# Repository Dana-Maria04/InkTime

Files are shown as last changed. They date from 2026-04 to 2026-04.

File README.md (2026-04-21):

# InkTime

## Block Diagram

Managed by the nRF52840 SoC, the device employs an RT6160 regulator to provide a steady 3.3V supply to all peripherals. The architecture combines an e-paper display and IMU with haptic feedback and dedicated user buttons.

Diagrama

## Bill of Materials (BOM)
| Qty | Value | Parts | Device | Package | Product Link | Datasheet Link |
| --: | --- | --- | --- | --- | --- | --- |
| 1 | nRF52840-QIAA | U1 | NORDIC_NRF_4_NRF52840_QF | AQFN-73-EP(7x7) | [JLCPCB](https://jlcpcb.com/partdetail/NordicSemicon-NRF52840_QIAAR/C190794) | [Datasheet](https://infocenter.nordicsemi.com/pdf/nRF52840_PS_v1.9.pdf) |
| 1 | BQ25180YBGR | IC1 | BQ25180YBGR | DSBGA-8(1.1x1.6) | [JLCPCB](https://jlcpcb.com/partdetail/TexasInstruments-BQ25180YBGR/C3682423) | [Datasheet](https://www.ti.com/lit/ds/symlink/bq25180.pdf) |
| 1 | MAX17048G+T10 | U3 | ESP32_C6_LIBRARY_MAX17048G+T10 | DFN-8-EP(2x2) | [JLCPCB](https://jlcpcb.com/partdetail/MaximIntegrated-MAX17048GT10/C2682616) | [Datasheet](https://www.analog.com/media/en/technical-documentation/data-sheets/MAX17048-MAX17049.pdf) |
| 1 | DRV2605YZFR | IC2 | DRV2605YZFR | DSBGA-9 | [JLCPCB](https://jlcpcb.com/partdetail/TexasInstruments-DRV2605YZFR/C81079) | [Datasheet](https://www.ti.com/lit/ds/symlink/drv2605.pdf) |
| 1 | DMG2305UX-7 | P-channel MOSFET | DMG2305UX-7 | SOT-23 | [JLCPCB](https://jlcpcb.com/partdetail/HXYMOSFET-DMG2305UX7/C5261054) | [Datasheet](https://www.diodes.com/assets/Datasheets/DMG2305UX.pdf) |
| 1 | SI1308EDL-T1-GE3  | Q3 | ESP32_C6_LIBRARY_6_SI1308EDL-T1-GE3 | SOT-323 | [JLCPCB](https://jlcpcb.com/partdetail/TECHPUBLIC-SI1308EDL/C7603347) | [Datasheet](https://www.vishay.com/docs/63399/si1308edl.pdf) |
| 3 | MBR0530 | D2, D4, D5 | MBR0530 | SOD-123 | [JLCPCB](https://jlcpcb.com/partdetail/4324765-MBR0530_F20000HF/C3757235) | [Datasheet](https://wmsc.lcsc.com/wmsc/upload/file/pdf/v2/lcsc/2205311800_Yangzhou-Yangjie-Electronic-Technology-MBR0530-F2-0000HF_C3757235.pdf) |
| 1 | USBLC6-2SC6Y | D3 | USBLC6-2SC6Y | SOT-23-6 | [JLCPCB](https://jlcpcb.com/partdetail/TECHPUBLIC-USBLC62SC6Y/C5310974) | [Datasheet](https://wmsc.lcsc.com/wmsc/upload/file/pdf/v2/lcsc/2401261525_TECH-PUBLIC-USBLC6-2SC6Y_C5310974.pdf) |
| 1 | 2450AT18B100E | ANT1 | 2450AT18B100E_2450AT18B100E | ANTC3216X140N / 1206 class | [JLCPCB](https://jlcpcb.com/partdetail/JohansonTechnology-2450AT18B100/C2836414) | [Datasheet](https://www.johansontechnology.com/datasheets/antennas/2450AT18B100.pdf) |
| 1 | KH-TYPE-C-16P | J4 | KH-TYPE-C-16P_KH-TYPE-C-16P | SMD | [JLCPCB](https://jlcpcb.com/partdetail/KH-TYPE-C-16P/C709357) | [Datasheet](https://wmsc.lcsc.com/wmsc/upload/file/pdf/v2/lcsc/2204251630_SHENZHEN-KINGHELM-Elec-KH-TYPE-C-16P_C709357.pdf) |
| 3 | EVP-AKE31A | SW_DN, SW_ENT, SW_UP | EVP-AKE31A | SW_EVP-AKE31A_PAN | [JLCPCB](https://jlcpcb.com/partdetail/PANASONIC-EVPAKE31A/C569760) | [Datasheet](https://www.lcsc.com/datasheet/C569760.pdf) |
| 1 | FTC252012SR47MBCA | L7 | MLP2016SR47MT0S1_FTC252012SR47MBCA  | INDC2016X100N | [JLCPCB](https://jlcpcb.com/partdetail/6763488-FTC252012SR47MBCA/C5832368) | [Datasheet](https://wmsc.lcsc.com/wmsc/upload/file/pdf/v2/lcsc/2311271530_TDK-FTC252012SR47MBCA_C5832368.pdf) |
| 1 | 32.768 kHz | X2 | NORDIC_NRF_1_XTAL_32KHZ | SMD3215-2P | [JLCPCB](https://jlcpcb.com/partdetail/NDK-NX3215SA_32_768K_STD_MUA9/C519280) | [Datasheet](https://www.ndk.com/images/products/crystal/resonator/NX3215SA_e.pdf) |
| 6 | 10K | R2_EP_DR, R5, R7, R8, R9, R_PWR_EPD | RC0201FR-1310KL | 0201 | [JLCPCB](https://jlcpcb.com/partdetail/YAGEO-RC0201FR1310KL/C6373588) | [Datasheet](https://www.lcsc.com/datasheet/C6373588.pdf) |
| 2 | 5K1 | R1_USB, R2_USB | RC0201FR-075K1L | 0201 | [JLCPCB](https://jlcpcb.com/partdetail/YAGEO-RC0201FR075K1L/C274341) | [Datasheet](https://www.lcsc.com/datasheet/C274341.pdf) |
| 2 | 3K3 | R17, R18 | RNCF0201DTC3K30 | 0201 | [JLCPCB](https://jlcpcb.com/partdetail/SEI_Stackpole_Elec-RNCF0201DTC3K30/C2487997) | [Datasheet](https://www.lcsc.com/datasheet/C2487997.pdf) |
| 3 | 0R | R2, R3, R4 | 0201WMJ0000TCE | 0201 | [JLCPCB](https://jlcpcb.com/partdetail/25793-0201WMJ0000TCE/C25050) | [Datasheet](https://www.lcsc.com/datasheet/C25050.pdf) |
| 1 | 2.2Î© | R_TYPE_SEL | 0201WMF220KTCE | 0201 | [JLCPCB](https://jlcpcb.com/partdetail/244650-0201WMF220KTCE/C247442) | [Datasheet](https://www.lcsc.com/datasheet/C247442.pdf) |
| 9 | 100nF | C5, C7, C8, C12, C19, C23, C27, C34, C42 | AC0201KRX6S6BB104 | 0201 | [JLCPCB](https://jlcpcb.com/partdetail/YAGEO-AC0201KRX6S6BB104/C3855913) | [Datasheet](https://www.lcsc.com/datasheet/C3855913.pdf) |
| 4 | 12pF | C1, C2, C17, C18 | 0201N120J250CT | 0201 | [JLCPCB](https://jlcpcb.com/partdetail/Walsin_TechCorp-0201N120J250CT/C424835) | [Datasheet](https://www.lcsc.com/datasheet/C424835.pdf) |
| 2 | 1pF | C3, C4 | GRM0335C1E1R0CA01J | 0201 | [JLCPCB](https://jlcpcb.com/partdetail/2274979-GRM0335C1E1R0CA01J/C2182912) | [Datasheet](https://www.lcsc.com/datasheet/C2182912.pdf) |
| 1 | 100pF | C11 | 0201N101F160CT | 0201 | [JLCPCB](https://jlcpcb.com/partdetail/Walsin_TechCorp-0201N101F160CT/C3847857) | [Datasheet](https://www.lcsc.com/datasheet/C3847857.pdf) |
| 1 | 47nF | C16 | C0201X5R473K160NTA | 0201 | [JLCPCB](https://jlcpcb.com/partdetail/126083-C0201X5R473K160NTA/C124806) | [Datasheet](https://www.lcsc.com/datasheet/C124806.pdf) |
| 1 | 1uF | C15 | CL05A105KP5NNNC | 0402 | [JLCPCB](https://jlcpcb.com/partdetail/C14445) | [Datasheet](https://www.lcsc.com/datasheet/C14445.pdf) |
| 5 | 4.7uF | C6, C14, C20, C21, C43 | GRM155R61A475KEAAD | 0402 | [JLCPCB](https://jlcpcb.com/partdetail/MurataElectronics-GRM155R61A475KEAAD/C77004) | [Datasheet](https://www.lcsc.com/datasheet/C77004.pdf) |
| 1 | 4.7uF / 25V | C2-EP-DR | C0402X5R475M250NT | 0402 | [JLCPCB](https://jlcpcb.com/partdetail/SANYEAR-C0402X5R475M250NT/C2911388) | [Datasheet](https://www.lcsc.com/datasheet/C2911388.pdf) |
| 9 | 1uF / 50V | EPD_C1, EPD_C2, EPD_C6, EPD_C7, EPD_C8, EPD_C9, EPD_C10, EPD_C11, EPD_C12 | GRM155R61H105KE05D | 0402 | [JLCPCB](https://jlcpcb.com/partdetail/1609005-GRM155R61H105KE05D/C1518208) | [Datasheet](https://www.lcsc.com/datasheet/C1518208.pdf) |
| 2 | 10uF | C24, C39 | 0402X106M100CT | 0402 | [JLCPCB](https://jlcpcb.com/partdetail/Walsin_TechCorp-0402X106M100CT/C2992625) | [Datasheet](https://www.lcsc.com/datasheet/C2992625.pdf) |
| 2 | 22uF | C25, C33 | CL05A226MQ6ZUN8 | 0402 | [JLCPCB](https://jlcpcb.com/partdetail/2889851-CL05A226MQ6ZUN8/C2762589) | [Datasheet](https://www.lcsc.com/datasheet/C2762589.pdf) |
| 1 | 820pF | C9 | MA0201XF821K250 | 0201 | [JLCPCB](https://jlcpcb.com/partdetail/Meritek-MA0201XF821K250/C3842403) | [Datasheet](https://www.lcsc.com/datasheet/C3842403.pdf) |
| 1 | 32MHz | X1 | NX2016SA-32MHZ-STD-CZS-5 | SMD2016-4P | [JLCPCB](https://jlcpcb.com/partdetail/NDK-NX2016SA_32MHZ_STD_CZS5/C843260) | [Datasheet](https://www.lcsc.com/datasheet/C843260.pdf) |
| 1 | 3.9nH | L1 | VHF060303H3N9ST | 0201 | [JLCPCB](https://jlcpcb.com/partdetail/153834-VHF060303H3N9ST/C142503) | [Datasheet](https://www.lcsc.com/datasheet/C142503.pdf) |
| 1 | 15nH | L3 | MLK0603L15NJT000 | 0201 | [JLCPCB](https://jlcpcb.com/partdetail/TDK-MLK0603L15NJT000/C6990407) | [Datasheet](https://www.lcsc.com/datasheet/C6990407.pdf) |
| 1 | BMA421 | IC3 | BMA421 | LGA-12(2x2) | [JLCPCB](https://jlcpcb.com/partdetail/BoschSensortec-BMA421/C5242966) | [Datasheet](https://files.pine64.org/doc/datasheet/pinetime/BST-BMA421-FL000.pdf) |
| 1 | RT6160AWSC | IC9 | RT6160AWSC | WLCSP-15B(2.3x1.4) | [JLCPCB](https://jlcpcb.com/partdetail/RichtekTech-RT6160AWSC/C7065276) | [Datasheet](https://www.mouser.com/datasheet/2/1458/DS6160A_03-3104604.pdf) |
| 1 | 503480-2400 | J1 | 5034802400 | 24-pin 0.5mm right-angle FPC | [JLCPCB](https://jlcpcb.com/partdetail/MOLEX-5034802400/C122434) | [Datasheet](https://www.mouser.com/datasheet/2/276/2/5034802400_FFC_FPC_CONNECTORS-1112921.pdf) |

## System Design and Hardware Implementation

The hardware architecture of the **InkTime Smartwatch** centers on the **nRF52840 microcontroller**, integrating five specialized sub-systems to create a high-efficiency wearable device.

### 1. Central SoC & Communication
The **nRF52840** handles all high-level logic, from sensor fusion to Bluetooth LE communication. It utilizes a **32 MHz crystal** for active processing and a **32.768 kHz crystal** for low-power timekeeping. For debugging and firmware updates, a **TC2030 SWD header** is included, exposing the `SWDIO` and `SWDCLK` lines.

### 2. Power Subsystem & Efficiency
Energy is managed through a multi-stage architecture:
* **USB-C Input:** Protected by **USBLC6-2SC6Y** ESD diodes to ensure safety during charging.
* **Management:** The **BQ25180 charger** regulates power flow between the USB source and the **Li-Po battery**.
* **Efficiency:** An **RT6160 Buck-Boost converter** ensures all peripherals receive exactly **3.3V**, regardless of battery discharge levels.
* **Monitoring:** The **MAX17048 fuel gauge** uses I2C to alert the MCU of low-battery conditions in real-time.

### 3. Specialized Sub-systems
* **Display:** The **1.54-inch E-Ink panel** uses an SPI interface. Its bi-stable nature allows it to hold an image without consuming power, drastically reducing the overall energy profile.
* **Motion & Interaction:** An **IMU (BMA421/423)** monitors activity, while three GPIO-mapped buttons manage user navigation and input.
* **Haptics:** Physical feedback for notifications is provided by a vibration motor controlled by the **DRV2605 driver**, which supports pre-programmed haptic patterns over I2C.

### 4. Energy Estimation
The system is optimized for an extremely low duty cycle:
* **Deep Sleep:** $< 10\text{µ}$.
* **Active Refresh:** $8\text{-}10\text{ mA}$ for approximately $1\text{-}2$ seconds per minute.

Based on the **250 mAh** battery capacity, the smartwatch achieves an autonomy of **over 9 days**, even with active sensor monitoring and daily haptic notifications. This performance highlights the synergy between the E-Ink technology and the nRF52's advanced power-saving features.

### Detailed Pinnout Map of nRF52840

| nRF52840 Pin | Connected Block | Signal Name | Purpose / Function |
| :--- | :--- | :--- | :--- |
| **P1.13** | E-paper Display | `MOSI` | SPI data output to display |
| **P1.15** | E-paper Display | `SCK` | SPI serial clock line |
| **P0.05** | E-paper Display | `EPD_CS` | SPI chip select (active low) |
| **P0.16** | E-paper Display | `EPD_DC` | Data/Command selection toggle |
| **P0.17** | E-paper Display | `EPD_RST` | Hardware reset for display |
| **P0.15** | E-paper Display | `EPD_BUSY` | Status feedback (busy/ready) |
| **P0.06** | I2C Bus (Shared) | `SDA` | Data line for IMU, Fuel Gauge, and Haptic |
| **P0.07** | I2C Bus (Shared) | `SCL` | Clock line for IMU, Fuel Gauge, and Haptic |
| **P0.08** | IMU (BMA42x) | `IMU_INT1` | Primary motion interrupt |
| **P1.08** | IMU (BMA42x) | `IMU_INT2` | Secondary motion interrupt |
| **P0.11** | PMIC (BQ25180) | `PMIC_INT` | Power-management status interrupt |
| **P0.24** | Fuel Gauge | `ALERT` | Battery fuel gauge status alert |
| **P0.12** | Haptic Driver | `HAPTIC_EN` | Enable and control for DRV2605 |
| **P0.13** | USB-C Interface | `D+` | USB differential data positive |
| **P0.14** | USB-C Interface | `D-` | USB differential data negative |
| **VBUS pin** | Charger / USB-C | `VBUS` | USB voltage presence detection |
| **SWDIO** | SWD Header | `SWDIO` | Bidirectional debug/programming data |
| **SWDCLK** | SWD Header | `SWDCLK` | Debug/programming clock reference |
| **P1.09** | SWD Header | `SWO` | Single Wire Output (trace debug) |
| **P0.18 / RESET** | SWD Header | `RESET` | Global hardware reset line |
| **ANT pin** | RF Network | `RF` | 2.4 GHz connection to chip antenna |

## Design Decisions & DRC/ERC Notes

### 1. Hardware Design Log
* **Space Optimization:** To fit the enclosure, a **1.0 mm PCB** was used with all components mounted on the **TOP layer**. The use of **0201 footprints** was critical for the high-density layout.
* **Signal Integrity:** **100 nF decoupling capacitors** are placed as close as possible ($< 0.5$ mm) to power pins. Power traces are widened to **0.3 mm** to ensure stable voltage delivery.
* **RF Layout:** The antenna is positioned on the board edge with a clear **Keep-out zone** (no copper on any layer) to maximize Bluetooth connectivity.

### 2. Validation & Manual Approvals
The following CAD warnings were reviewed and approved based on project constraints:

* **Mechanical Alignment (DRC):** Dimension errors for the **USB-C connector and tactile buttons** were ignored because their placement must match the pre-defined enclosure openings.
* **High-Density Routing (DRC):** Overlaps caused by **via-in-pad** and escape routing for the nRF52840 were accepted. This was the only way to route the MCU pins in the available space.
* **Net Connectivity (ERC):** "Only INPUT pins" warnings were verified; the schematic is functionally complete, and these are typical false positives in this project context.
* **Power Pins (ERC):** Power rail warnings were manually checked to ensure that the **RT6160** and **BQ25180** correctly supply the 3.3V and VBAT nets.

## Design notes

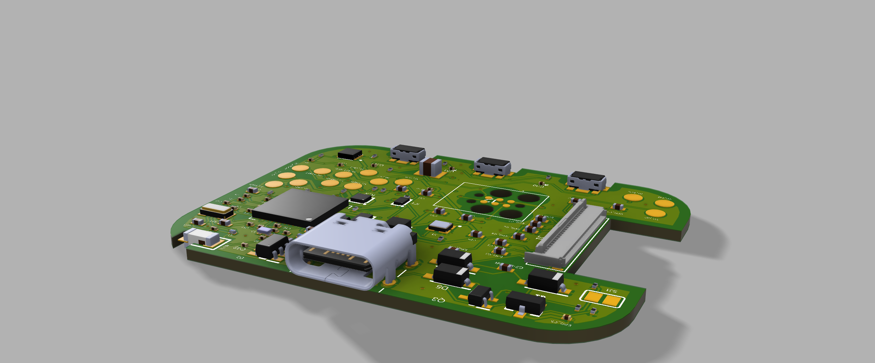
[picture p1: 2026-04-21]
Images/3D_PCB_View2.png

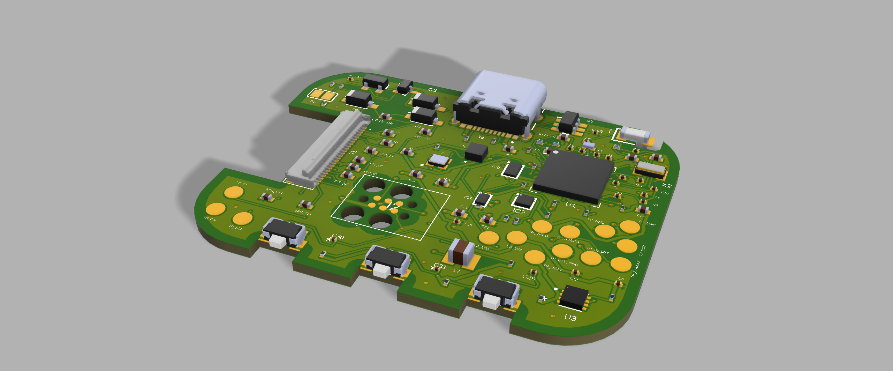
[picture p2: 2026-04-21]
Images/3D_PCB_View1.png

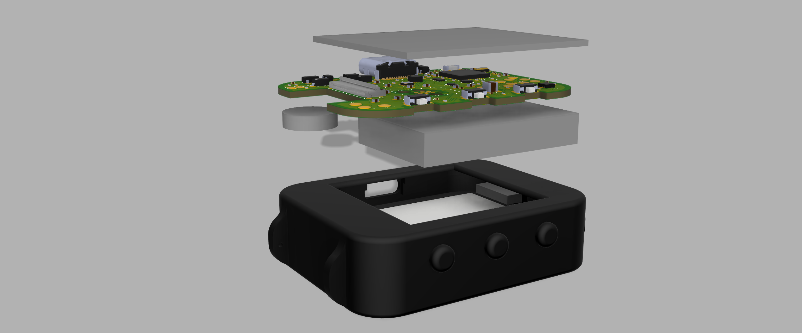
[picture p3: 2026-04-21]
Images/ExplodedView.png

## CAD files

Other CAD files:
Mechanical/InkTime_Assembly.f3z

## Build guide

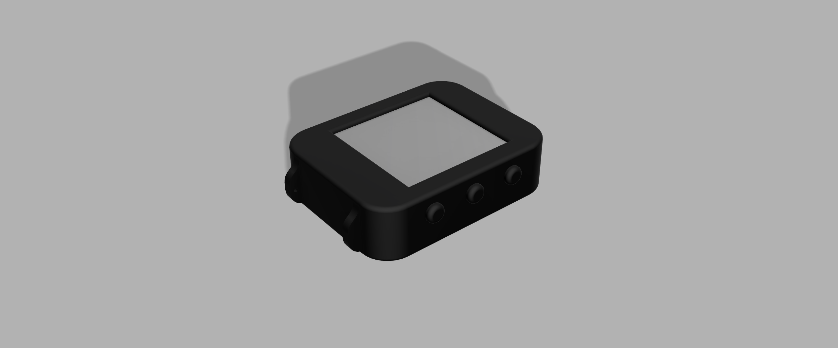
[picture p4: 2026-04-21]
Images/Assembly.png

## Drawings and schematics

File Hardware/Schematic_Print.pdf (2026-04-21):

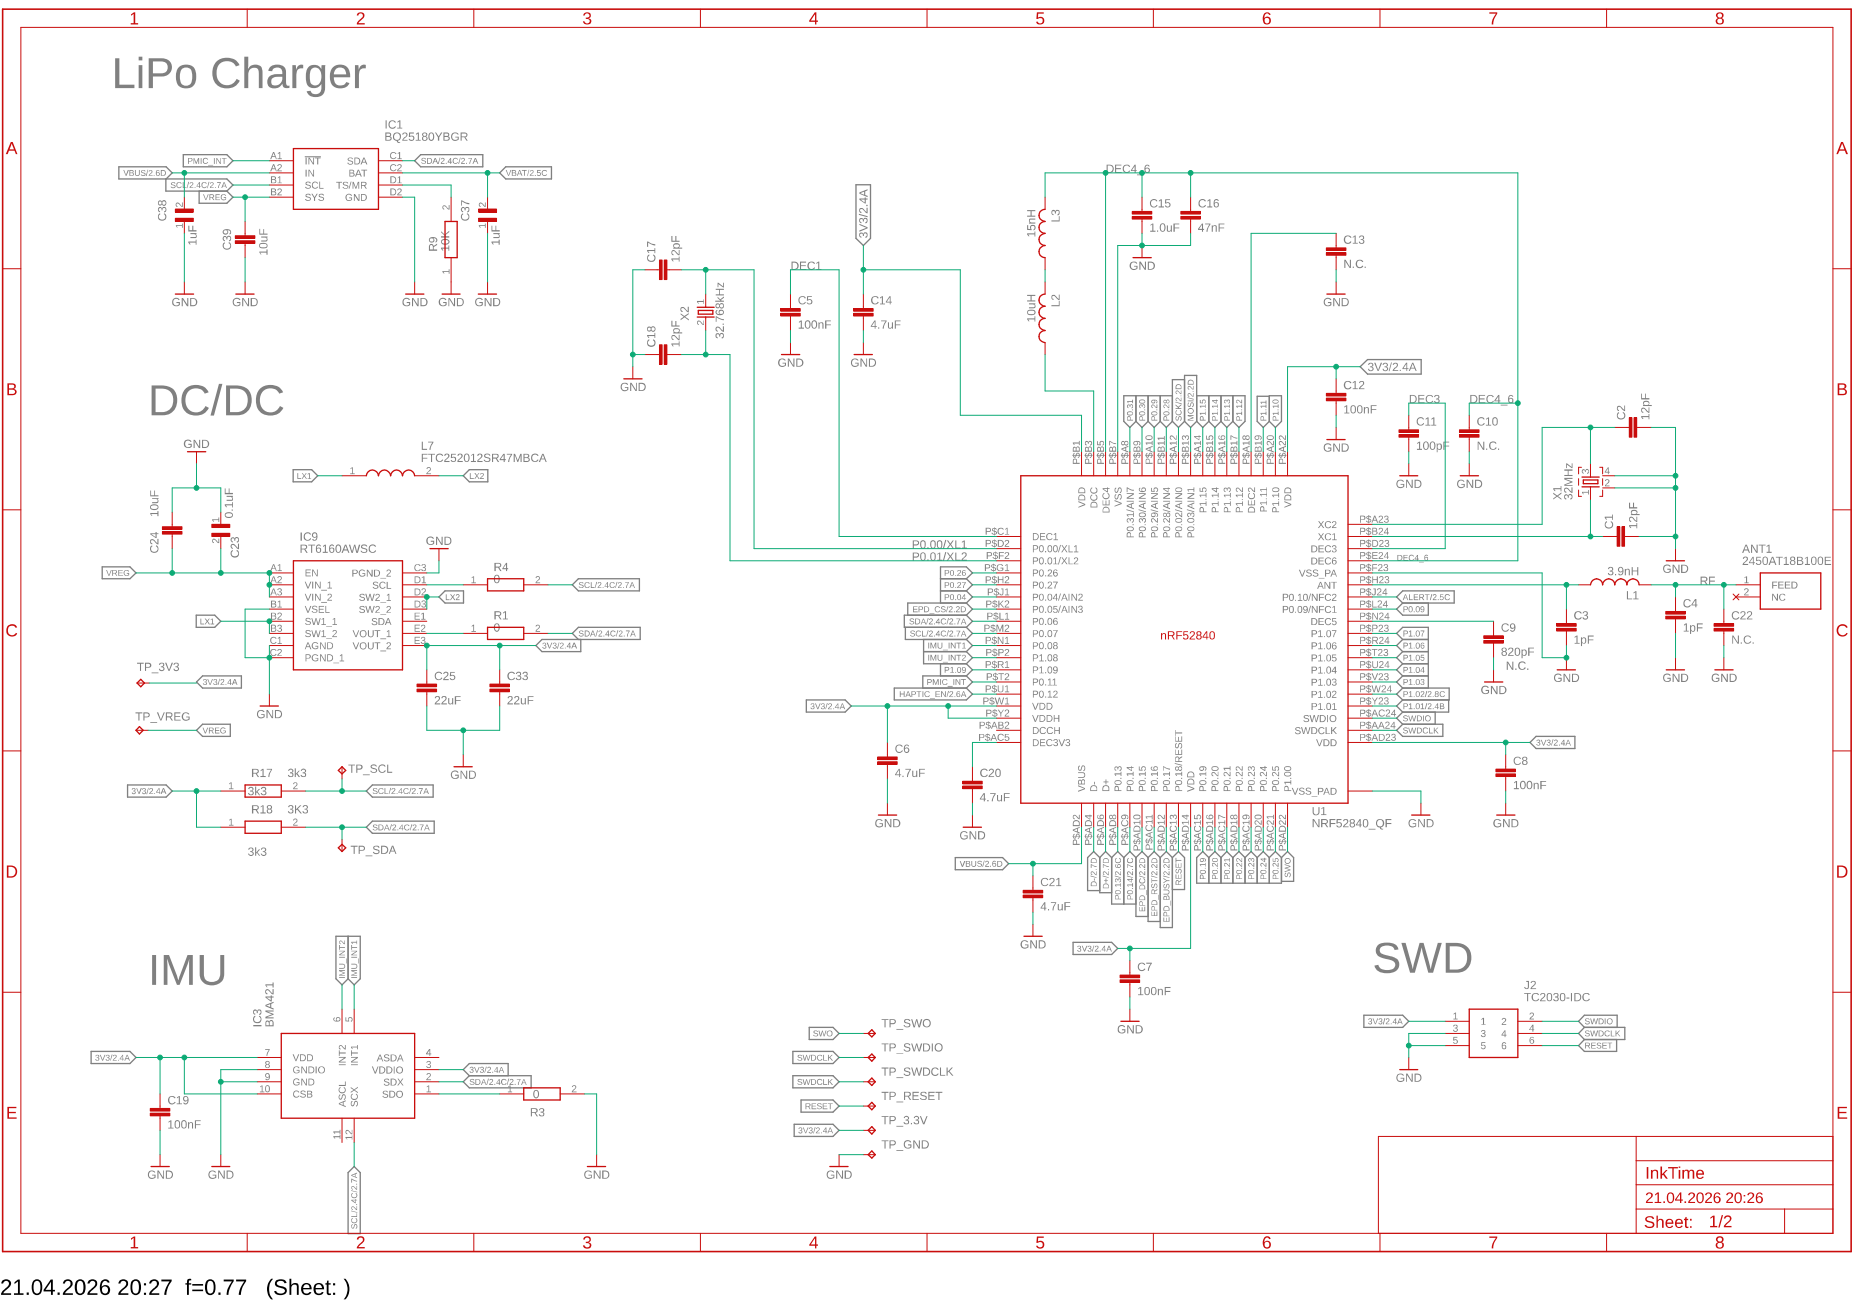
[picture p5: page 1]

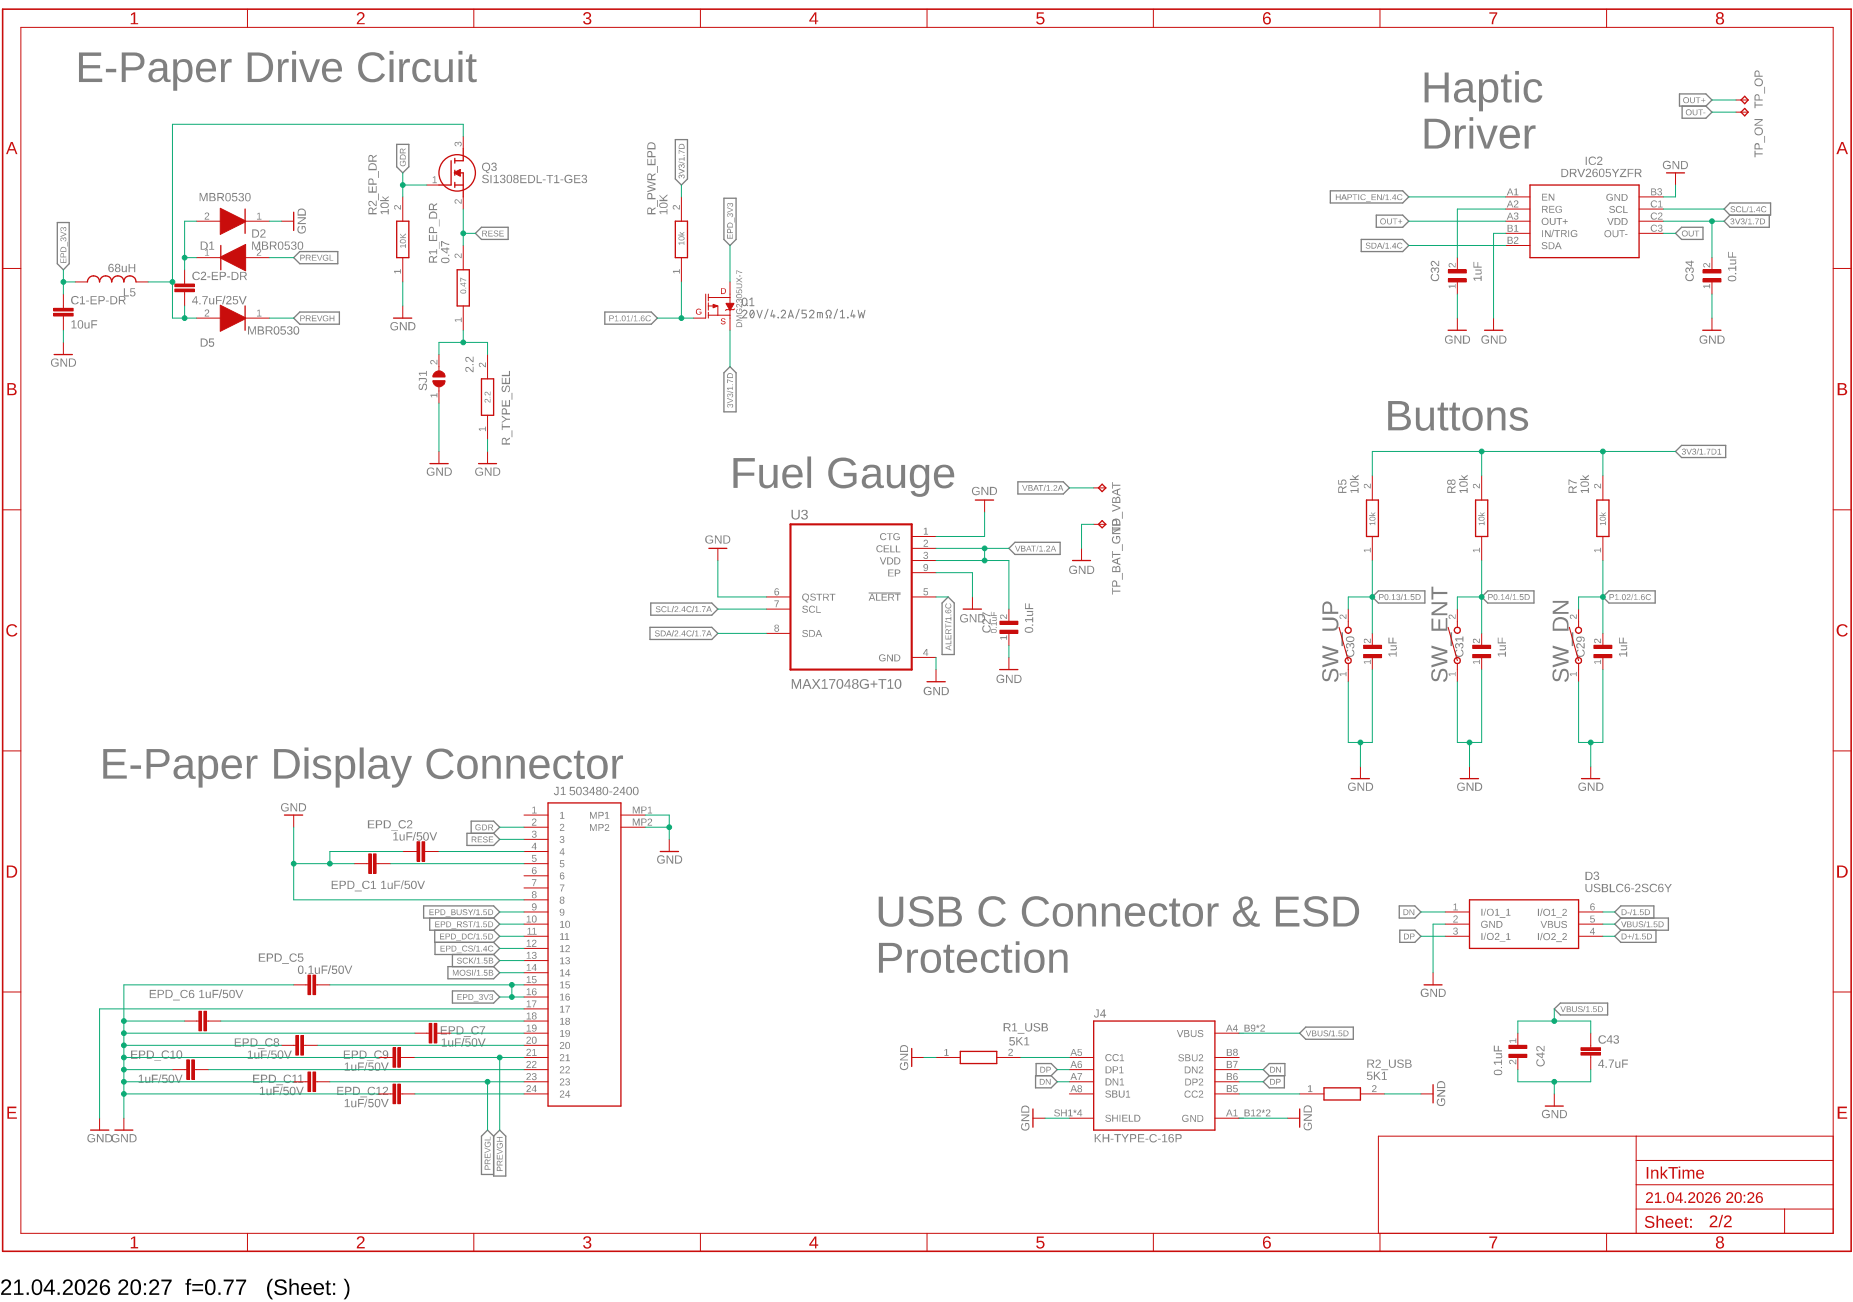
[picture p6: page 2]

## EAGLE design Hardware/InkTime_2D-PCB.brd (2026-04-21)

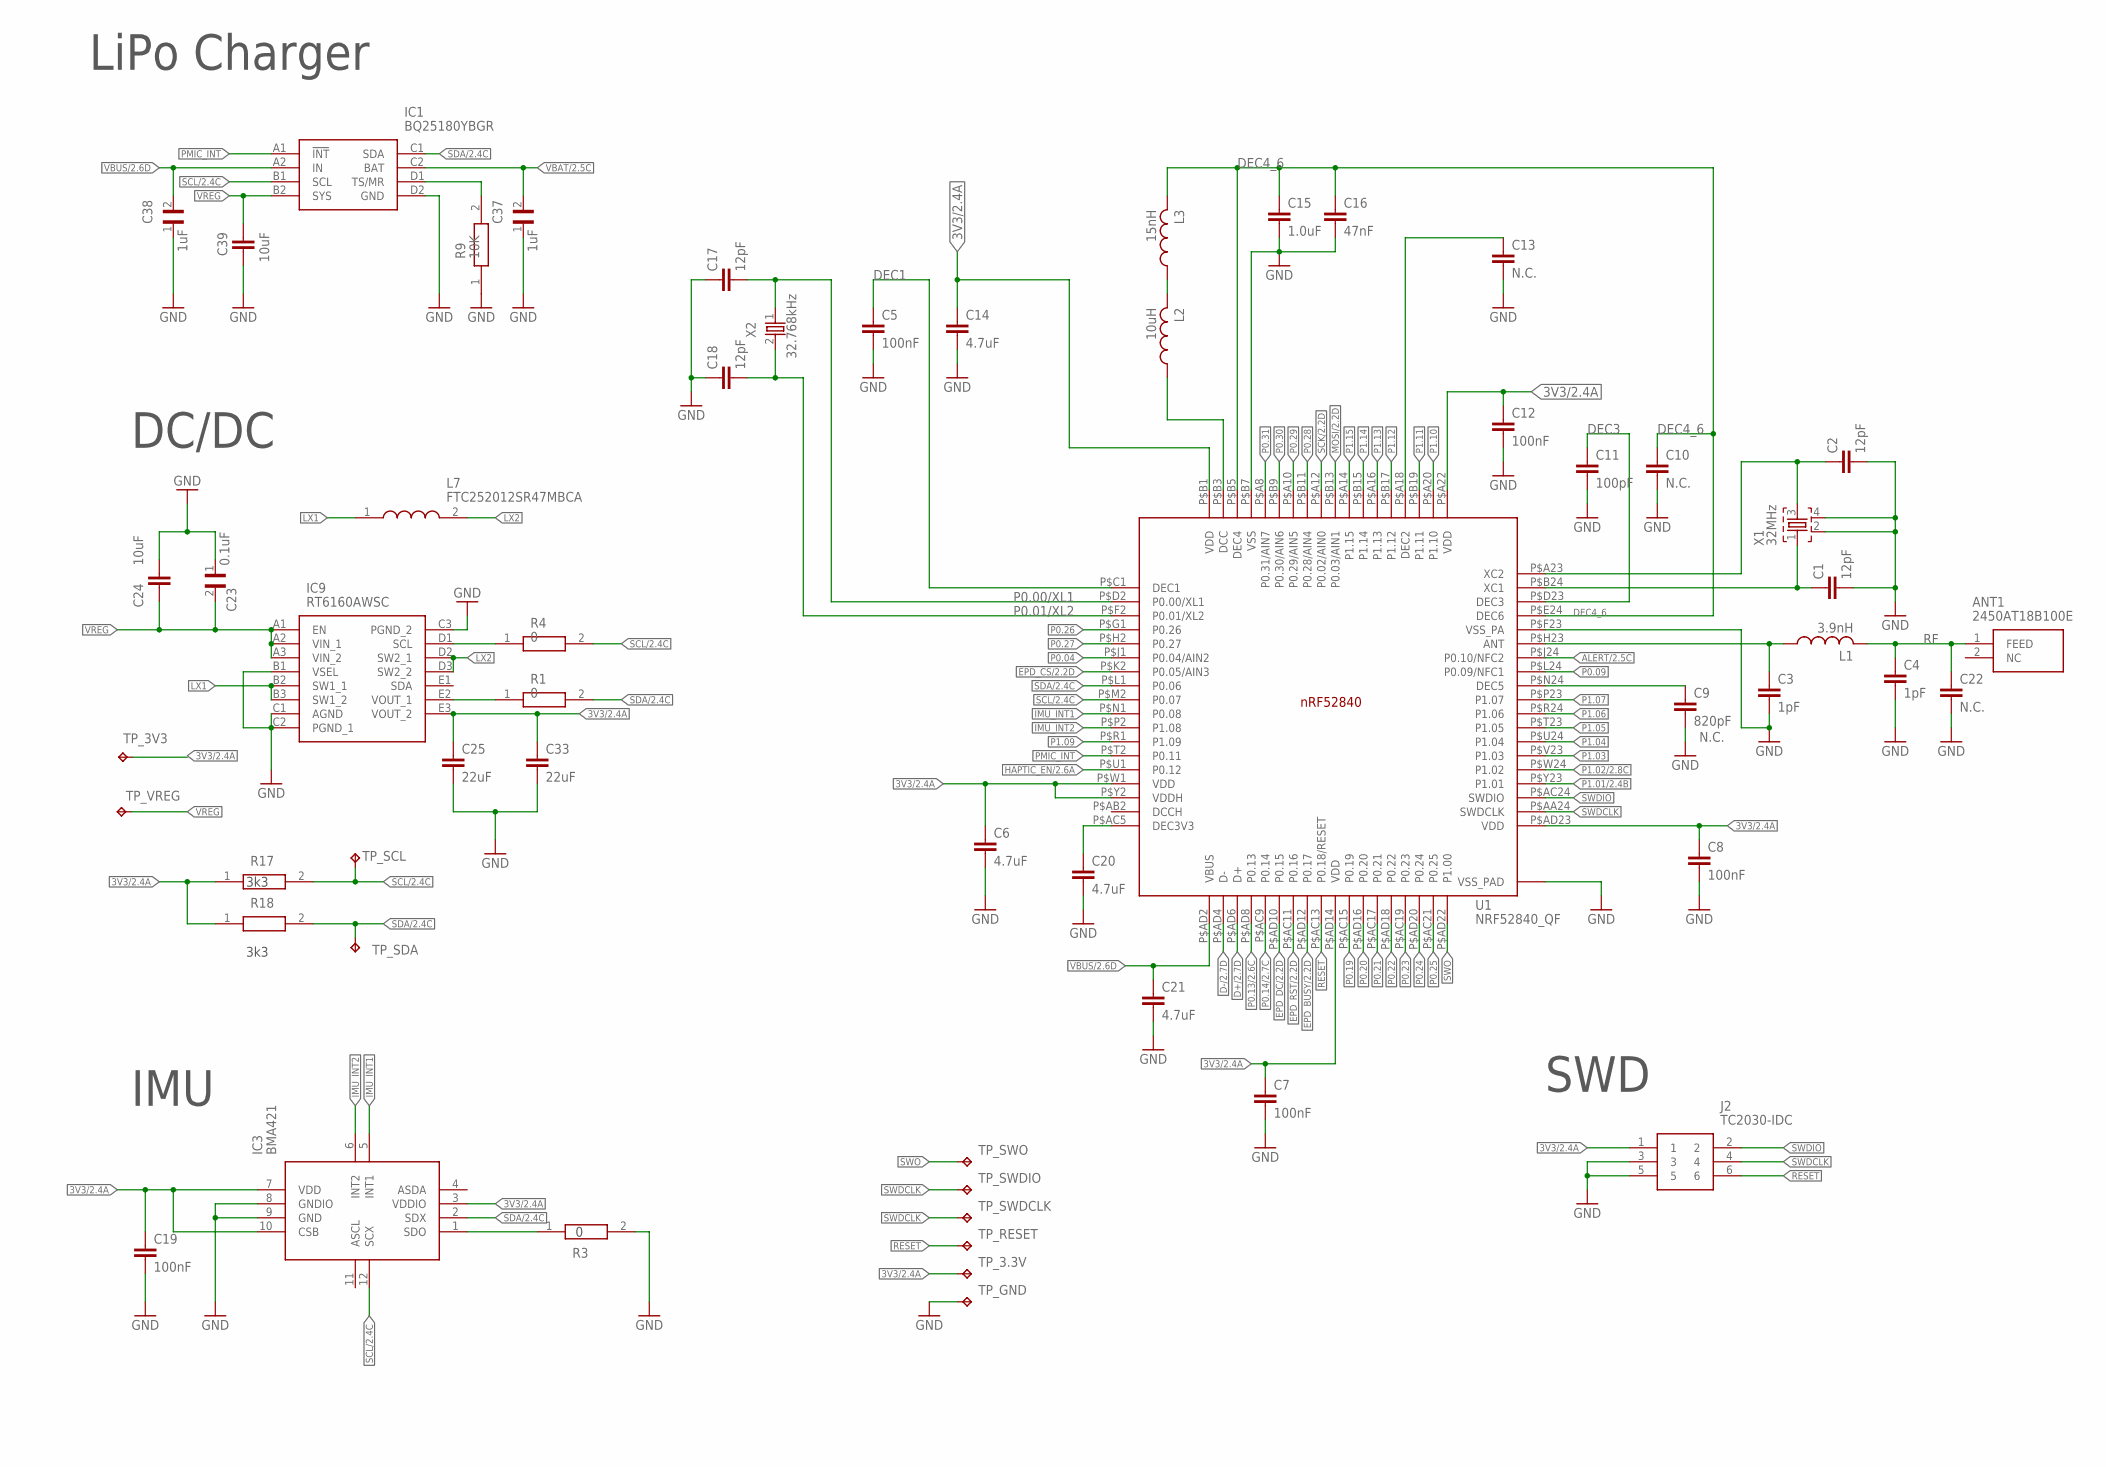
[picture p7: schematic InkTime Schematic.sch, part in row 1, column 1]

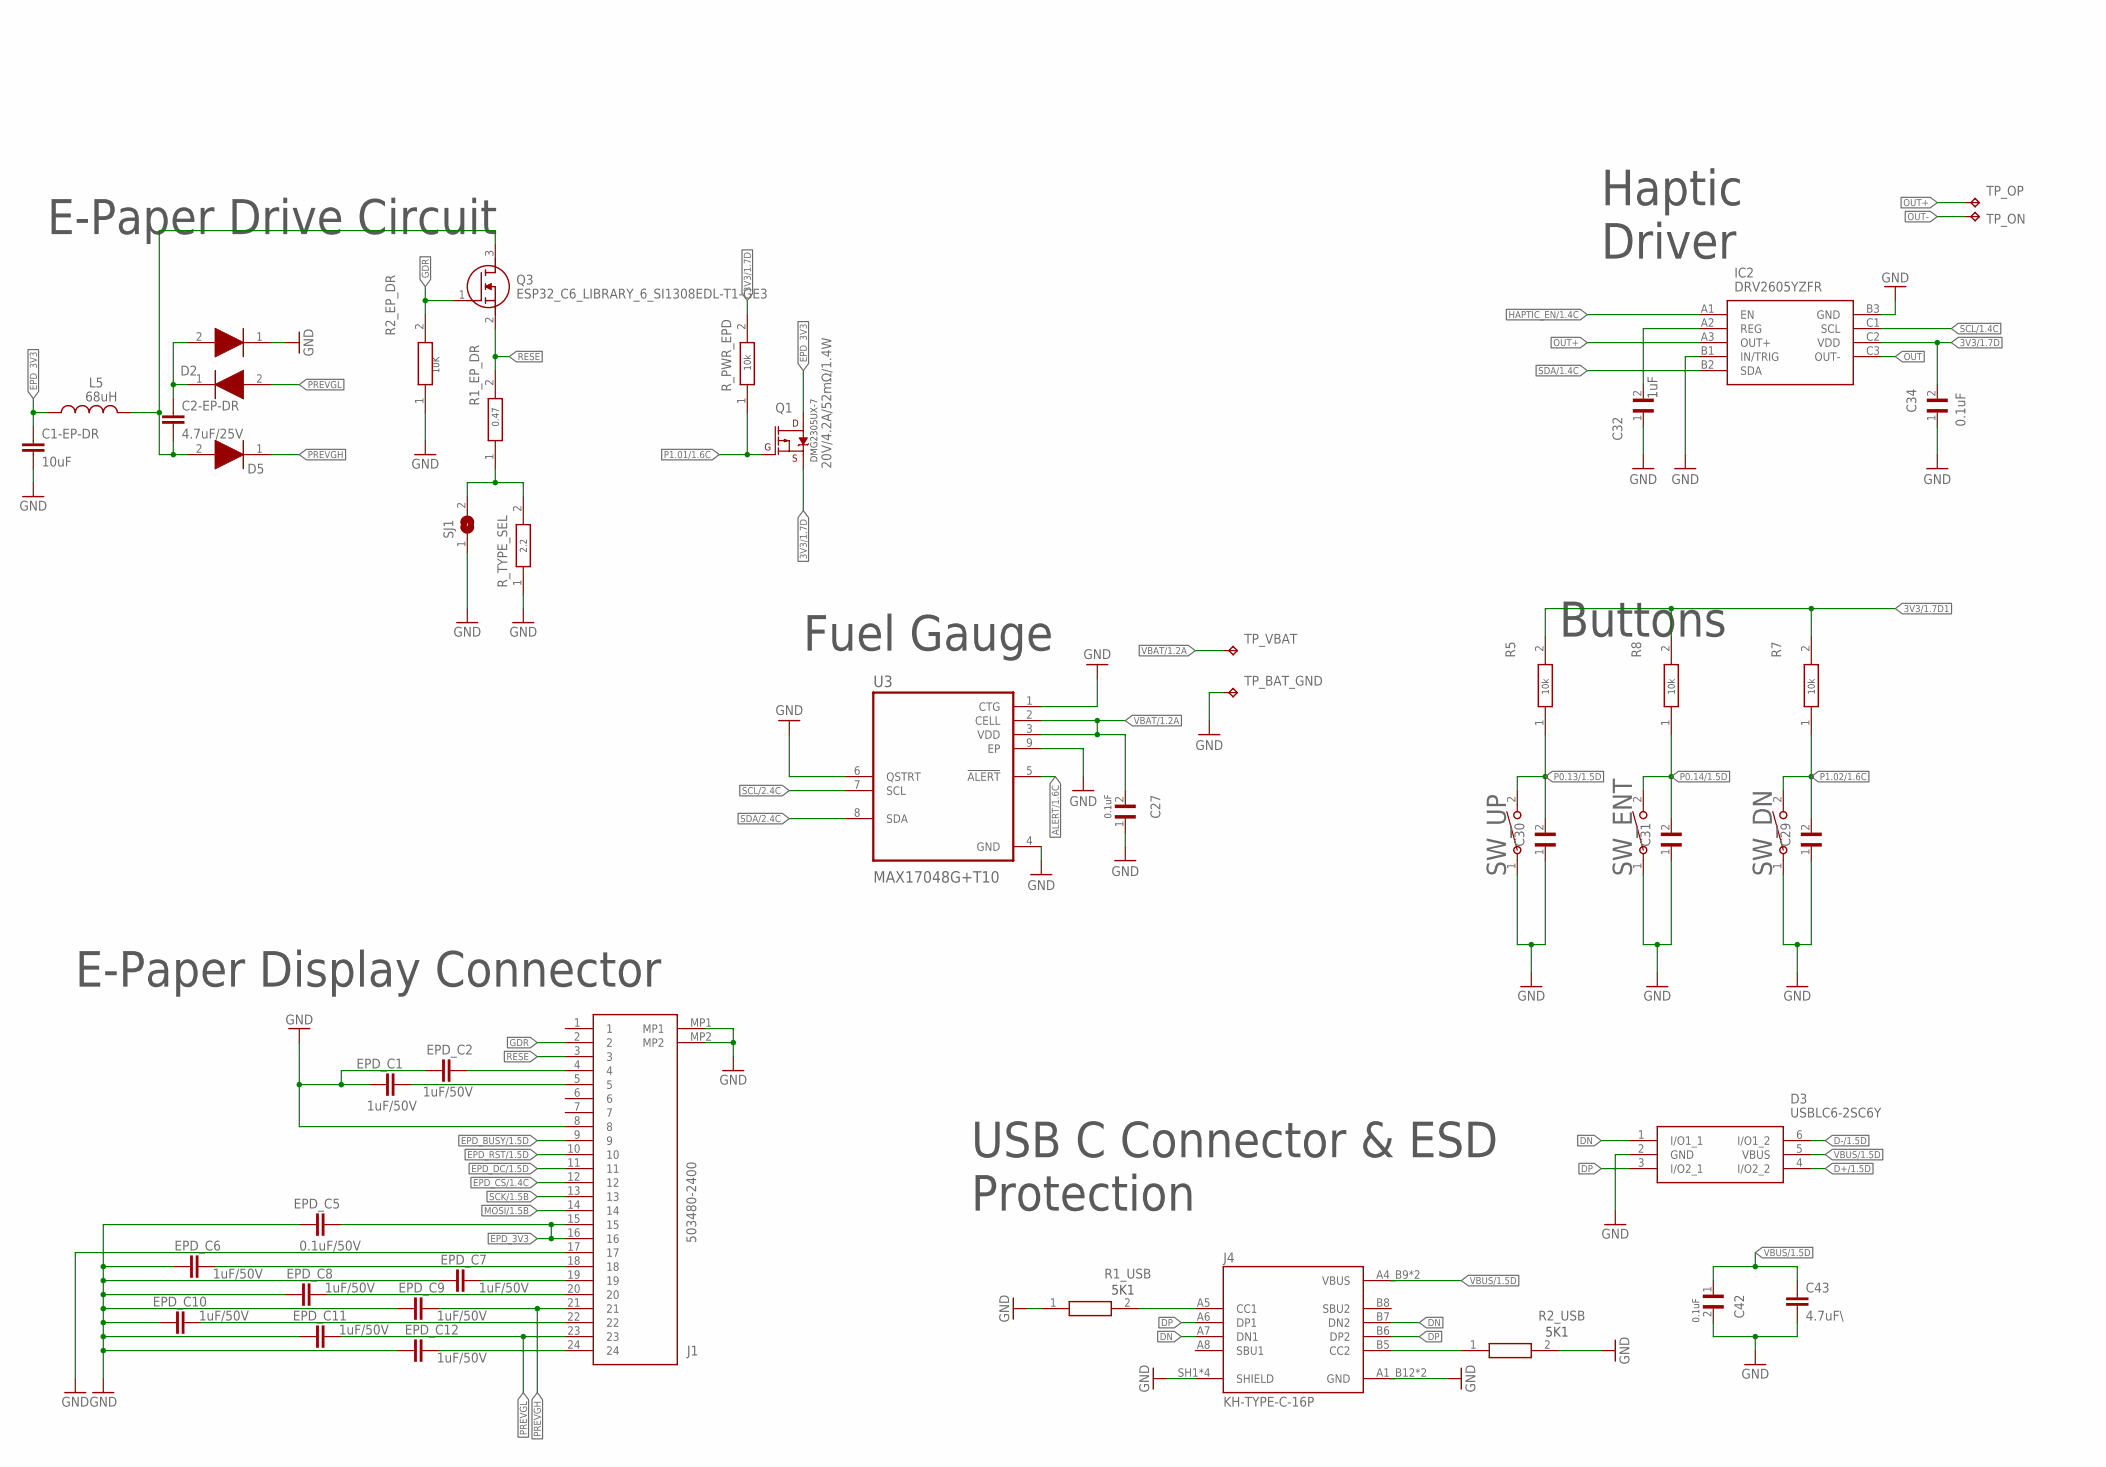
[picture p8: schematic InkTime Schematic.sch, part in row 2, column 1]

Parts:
ANT1: 2450AT18B100E; 2450AT18B100E_ANTC3216X140N
C1, C2, C17, C18: 12pF; NORDIC_NRF_3_RESC0201_L
C1-EP-DR, C24, C39: 10uF; NORDIC_NRF_3_RESC0402_L
C2-EP-DR: 4.7uF/25V; NORDIC_NRF_3_RESC0402_L
C3, C4: 1pF; NORDIC_NRF_3_RESC0201_L
C5, C7, C8, C12, C19: 100nF; NORDIC_NRF_3_RESC0201_L
C6, C14: 4.7uF; NORDIC_NRF_3_RESC0402_L
C9: 820pF; NORDIC_NRF_3_RESC0201_L
C10, C13, C22: N.C.; NORDIC_NRF_3_RESC0201_L
C11: 100pF; NORDIC_NRF_3_RESC0201_L
C15: 1.0uF; NORDIC_NRF_3_RESC0402_L
C16: 47nF; NORDIC_NRF_3_RESC0201_L
C20, C21: 4.7uF; PERFECT_0402_0402
C23, C27, C34: 0.1uF; GRM011R60J152KE01L_1_0201
C25, C33: 22uF; NORDIC_NRF_3_RESC0402_L
C29, C30, C31: 1uF; GRM011R60J152KE01L_2_CAPC0201X13N
C32, C37, C38: 1uF; GRM011R60J152KE01L_1_0201
C42: 0.1uF; GRM011R60J152KE01L_2_CAPC0201X13N
C43: 4.7uF\; NORDIC_NRF_3_RESC0402_L
D1: MBR0530; ESP32_C6_LIBRARY_5_SOD3716X135N
D2, D5: ESP32_C6_LIBRARY_5_MBR0530; ESP32_C6_LIBRARY_5_SOD3716X135N
D3: USBLC6-2SC6Y; ESP32_C6_LIBRARY_3_SOT95P280X145-6N
EPD_C1, EPD_C2, EPD_C6, EPD_C7, EPD_C8, EPD_C9, EPD_C10, EPD_C11, EPD_C12: 1uF/50V; NORDIC_NRF_3_RESC0402_L
EPD_C5: 0.1uF/50V; NORDIC_NRF_3_RESC0201_L
IC1: BQ25180YBGR; BQ25180YBGR_BGA8C40P2X4_100X155X50
IC2: DRV2605YZFR; DRV2605YZFR_BGA9C50P3X3_144X144X62
IC3: BMA421; BMA423_BMA423
IC9: RT6160AWSC; RT6160AWSC_BGA15C40P3X5_140X230X60
J1: 503480-2400; 503480-2400_5034802400
J2: TC2030-IDC; TC2030-IDC_TC2030IDC
J4: KH-TYPE-C-16P; KH-TYPE-C-16P_KINGHELM_KH-TYPE-C-16P
L1: 3.9nH; NORDIC_NRF_2_RESC0201_L
L2: 10uH; NORDIC_NRF_2_RESC0201_L
L3: 15nH; NORDIC_NRF_2_RESC0201_L
L5: 68uH; NORDIC_NRF_2_RESC0402_L
L7: FTC252012SR47MBCA; MLP2016SR47MT0S1_INDC2016X100N
Q1: 20V/4.2A/52mΩ/1.4W; ESP32_C6_LIBRARY_4_ESP32_C6_LIBRARY_4_ESP32_C6_LIBRARY_4_ES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
Q3: ESP32_C6_LIBRARY_6_SI1308EDL-T1-GE3; ESP32_C6_LIBRARY_6_SOT65P210X110-3N
R1, R3, R4: 0; ERA-1AEB3401C_0201
R1_EP_DR: 0.47; CPF0201D7K68C1_0201
R1_USB, R2_USB: 5K1; CPF0201D7K68C1_0201
R2_EP_DR, R5, R7, R8: 10k; CPF0201D7K68C1_0201
R9: 10K; ERA-1AEB3401C_0201
R17: 3k3; ERA-1AEB3401C_0201
R18: 3K3; ERA-1AEB3401C_0201
R_PWR_EPD: 10K; CPF0201D7K68C1_0201
R_TYPE_SEL: 2.2; CPF0201D7K68C1_0201
SJ1: ESP32_C6_LIBRARY_7_JUMPER_SJ
SW_DN: 2025-10-22_07-23-44_LIBRARY_EVP-AKE31ASW_EVP-AKE3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; 2025-10-22_07-23-44_LIBRARY_SW_EVP-AKE31A_PAN
SW_ENT: 2025-10-22_07-23-44_LIBRARY_EVP-AKE31ASW_EVP-AKE3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; 2025-10-22_07-23-44_LIBRARY_SW_EVP-AKE31A_PAN
SW_UP: 2025-10-22_07-23-44_LIBRARY_EVP-AKE31ASW_EVP-AKE3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; 2025-10-22_07-23-44_LIBRARY_SW_EVP-AKE31A_PAN
TP_3.3V, TP_3V3: HECTOR_WATCH_1_TPTP20R; HECTOR_WATCH_1_TP20R
TP_BAT_GND: HECTOR_WATCH_1_TPTP20R; HECTOR_WATCH_1_TP20R
TP_GND: HECTOR_WATCH_1_TPTP20R; HECTOR_WATCH_1_TP20R
TP_ON: HECTOR_WATCH_1_TPTP20R; HECTOR_WATCH_1_TP20R
TP_OP: HECTOR_WATCH_1_TPTP20R; HECTOR_WATCH_1_TP20R
TP_RESET: HECTOR_WATCH_1_TPTP20R; HECTOR_WATCH_1_TP20R
TP_SCL: HECTOR_WATCH_1_TPTP20R; HECTOR_WATCH_1_TP20R
TP_SDA: HECTOR_WATCH_1_TPTP20R; HECTOR_WATCH_1_TP20R
TP_SWDCLK: HECTOR_WATCH_1_TPTP20R; HECTOR_WATCH_1_TP20R
TP_SWDIO: HECTOR_WATCH_1_TPTP20R; HECTOR_WATCH_1_TP20R
TP_SWO: HECTOR_WATCH_1_TPTP20R; HECTOR_WATCH_1_TP20R
TP_VBAT: HECTOR_WATCH_1_TPTP20R; HECTOR_WATCH_1_TP20R
TP_VREG: HECTOR_WATCH_1_TPTP20R; HECTOR_WATCH_1_TP20R
U1: NRF52840_QF; NORDIC_NRF_4_AQFN50P700X700X85_HS-74N
U3: MAX17048G+T10; ESP32_C6_LIBRARY_SON50P200X200X80-9N
X1: 32MHz; NORDIC_NRF_BT-XTAL_2016_N
X2: 32.768kHz; NORDIC_NRF_1_XTAL_3215_N

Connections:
3V3/1.7D: C34.2, IC2.C2 (VDD), Q1.2 (S), R_PWR_EPD.2
3V3/1.7D1: R5.2, R7.2, R8.2
3V3/2.4A: C6.1, C7.1, C8.1, C12.1, C14.1, C19.1, C25.1, C33.1, IC3.3 (VDDIO), IC3.7 (VDD), IC3.10 (CSB), IC9.E3 (VOUT_2), J2.1, R17.1, R18.1, TP_3.3V.TP, TP_3V3.TP, U1.P$A22 (VDD), U1.P$AD14 (VDD), U1.P$AD23 (VDD), U1.P$B1 (VDD), U1.P$W1 (VDD), U1.P$Y2 (VDDH)
ALERT/1.6C: U3.5 (!ALERT)
ALERT/2.5C: U1.P$J24 (P0.10/NFC2)
D+/1.5D: D3.4 (I/O2_2)
D+/2.7D: U1.P$AD6 (D+)
D-/1.5D: D3.6 (I/O1_2)
D-/2.7D: U1.P$AD4 (D-)
DEC1: C5.1, U1.P$C1 (DEC1)
DEC3: C11.1, U1.P$D23 (DEC3)
DEC4_6: C10.1, C15.1, C16.1, L3.2, U1.P$B5 (DEC4), U1.P$E24 (DEC6)
DN: D3.1 (I/O1_1), J4.A7 (DN1), J4.B7 (DN2)
DP: D3.3 (I/O2_1), J4.A6 (DP1), J4.B6 (DP2)
EPD_3V3: C1-EP-DR.1, EPD_C5.2, J1.15, J1.16, L5.1, Q1.3 (D)
EPD_BUSY/1.5D: J1.9
EPD_BUSY/2.2D: U1.P$AD12 (P0.17)
EPD_CS/1.4C: J1.12
EPD_CS/2.2D: U1.P$K2 (P0.05/AIN3)
EPD_DC/1.5D: J1.11
EPD_DC/2.2D: U1.P$AD10 (P0.15)
EPD_RST/1.5D: J1.10
EPD_RST/2.2D: U1.P$AC11 (P0.16)
GDR: J1.2, Q3.1 (G), R2_EP_DR.2
GND: C1.2, C1-EP-DR.2, C2.2, C3.2, C4.2, C5.2, C6.2, C7.2, C8.2, C11.2, C12.2, C13.2, C14.2, C17.1, C18.1, C19.2, C20.2, C21.2, C22.2, C23.1, C24.1, C25.2, C27.1, C29.1, C30.1, C31.1, C32.1, C33.2, C34.1, C37.1, C38.1, C39.1, C42.2, C43.2, D1.1 (K), D3.2 (GND), EPD_C1.1, EPD_C2.1, EPD_C5.1, EPD_C6.1, EPD_C7.1, EPD_C8.1, EPD_C9.1, EPD_C10.1, EPD_C11.1, EPD_C12.1, IC1.D2 (GND), IC2.B1 (IN/TRIG), IC2.B3 (GND), IC3.8 (GNDIO), IC3.9 (GND), IC9.B1 (VSEL), IC9.C1 (AGND), IC9.C2 (PGND_1), IC9.C3 (PGND_2), J1.8, J1.17, J1.MP1, J1.MP2, J2.3, J2.5, J4.A1_B12 (GND), J4.A12_B1 (GND), J4.SH1 (SHIELD), J4.SH2 (SHIELD), J4.SH3 (SHIELD), J4.SH4 (SHIELD), R1_USB.1, R2_EP_DR.1, R2_USB.2, R3.2, R9.1, R_TYPE_SEL.1, SJ1.1, SW_DN.1, SW_ENT.1, SW_UP.1, TP_BAT_GND.TP, TP_GND.TP, U1.P$74 (VSS_PAD), U1.P$75 (VSS_PAD), U1.P$76 (VSS_PAD), U1.P$77 (VSS_PAD), U1.P$78 (VSS_PAD), U1.P$79 (VSS_PAD), U1.P$80 (VSS_PAD), U1.P$81 (VSS_PAD), U1.P$82 (VSS_PAD), U1.P$83 (VSS_PAD), U1.P$84 (VSS_PAD), U1.P$85 (VSS_PAD), U1.P$86 (VSS_PAD), U1.P$87 (VSS_PAD), U1.P$88 (VSS_PAD), U1.P$89 (VSS_PAD), U1.P$90 (VSS_PAD), U1.P$F23 (VSS_PA), U3.1 (CTG), U3.4 (GND), U3.6 (QSTRT), U3.9 (EP), X1.2, X1.4
HAPTIC_EN/1.4C: IC2.A1 (EN)
HAPTIC_EN/2.6A: U1.P$U1 (P0.12)
IMU_INT1: IC3.5 (INT1), U1.P$N1 (P0.08)
IMU_INT2: IC3.6 (INT2), U1.P$P2 (P1.08)
LX1: IC9.B2 (SW1_1), IC9.B3 (SW1_2), L7.1
LX2: IC9.D2 (SW2_1), IC9.D3 (SW2_2), L7.2
MOSI/1.5B: J1.14
MOSI/2.2D: U1.P$B13 (P0.03/AIN1)
unnamed: C20.1, U1.P$AC5 (DEC3V3)
unnamed: C9.1, U1.P$N24 (DEC5)
unnamed: C13.1, U1.P$A18 (DEC2)
unnamed: L2.2, L3.1
unnamed: C15.2, C16.2, U1.P$B7 (VSS)
unnamed: L2.1, U1.P$B3 (DCC)
unnamed: C3.1, L1.1, U1.P$H23 (ANT)
unnamed: C2.1, U1.P$A23 (XC2), X1.3
unnamed: C1.1, U1.P$B24 (XC1), X1.1
unnamed: EPD_C2.2, J1.4
unnamed: IC9.D1 (SCL), R4.1
unnamed: EPD_C10.2, J1.22
unnamed: IC9.E2 (VOUT_1), R1.1
unnamed: EPD_C1.2, J1.5
unnamed: IC1.D1 (TS/MR), R9.2
unnamed: IC3.1 (SDO), R3.1
unnamed: EPD_C6.2, J1.18
unnamed: EPD_C7.2, J1.19
unnamed: EPD_C12.2, J1.24
unnamed: EPD_C8.2, J1.20
unnamed: C32.2, IC2.A2 (REG)
unnamed: C2-EP-DR.2, D5.2 (A), L5.2, Q3.3 (D)
unnamed: C2-EP-DR.1, D1.2 (A), D2.1 (K)
unnamed: R1_EP_DR.1, R_TYPE_SEL.2, SJ1.2
unnamed: J4.A5 (CC1), R1_USB.2
unnamed: J4.B5 (CC2), R2_USB.1
N.C.: C9.2, C10.2
OUT: IC2.C3 (OUT-)
OUT+: IC2.A3 (OUT+), TP_OP.TP
OUT-: TP_ON.TP
P0.00/XL1: C17.2, U1.P$D2 (P0.00/XL1), X2.1
P0.01/XL2: C18.2, U1.P$F2 (P0.01/XL2), X2.2
P0.04: U1.P$J1 (P0.04/AIN2)
P0.09: U1.P$L24 (P0.09/NFC1)
P0.13/1.5D: C30.2, R5.1, SW_UP.2
P0.13/2.6C: U1.P$AD8 (P0.13)
P0.14/1.5D: C31.2, R8.1, SW_ENT.2
P0.14/2.7C: U1.P$AC9 (P0.14)
P0.19: U1.P$AC15 (P0.19)
P0.20: U1.P$AD16 (P0.20)
P0.21: U1.P$AC17 (P0.21)
P0.22: U1.P$AD18 (P0.22)
P0.23: U1.P$AC19 (P0.23)
P0.24: U1.P$AD20 (P0.24)
P0.25: U1.P$AC21 (P0.25)
P0.26: U1.P$G1 (P0.26)
P0.27: U1.P$H2 (P0.27)
P0.28: U1.P$B11 (P0.28/AIN4)
P0.29: U1.P$A10 (P0.29/AIN5)
P0.30: U1.P$B9 (P0.30/AIN6)
P0.31: U1.P$A8 (P0.31/AIN7)
P1.01/1.6C: Q1.1 (G), R_PWR_EPD.1
P1.01/2.4B: U1.P$Y23 (P1.01)
P1.02/1.6C: C29.2, R7.1, SW_DN.2
P1.02/2.8C: U1.P$W24 (P1.02)
P1.03: U1.P$V23 (P1.03)
P1.04: U1.P$U24 (P1.04)
P1.05: U1.P$T23 (P1.05)
P1.06: U1.P$R24 (P1.06)
P1.07: U1.P$P23 (P1.07)
P1.09: U1.P$R1 (P1.09)
P1.10: U1.P$A20 (P1.10)
P1.11: U1.P$B19 (P1.11)
P1.12: U1.P$B17 (P1.12)
P1.13: U1.P$A16 (P1.13)
P1.14: U1.P$B15 (P1.14)
P1.15: U1.P$A14 (P1.15)
PMIC_INT: IC1.A1 (!INT), U1.P$T2 (P0.11)
PREVGH: D5.1 (K), EPD_C9.2, J1.21
PREVGL: D2.2 (A), EPD_C11.2, J1.23
RESE: J1.3, Q3.2 (S), R1_EP_DR.2
RESET: J2.6, TP_RESET.TP, U1.P$AC13 (P0.18/RESET)
RF: ANT1.1 (FEED), C4.1, C22.1, L1.2
SCK/1.5B: J1.13
SCK/2.2D: U1.P$A12 (P0.02/AIN0)
SCL/1.4C: IC2.C1 (SCL)
SCL/2.4C: IC1.B1 (SCL), IC3.12 (SCX), R4.2, R17.2, TP_SCL.TP, U1.P$M2 (P0.07), U3.7 (SCL)
SDA/1.4C: IC2.B2 (SDA)
SDA/2.4C: IC1.C1 (SDA), IC3.2 (SDX), R1.2, R18.2, TP_SDA.TP, U1.P$L1 (P0.06), U3.8 (SDA)
SWDCLK: J2.4, TP_SWDCLK.TP, TP_SWDIO.TP, U1.P$AA24 (SWDCLK)
SWDIO: J2.2, U1.P$AC24 (SWDIO)
SWO: TP_SWO.TP, U1.P$AD22 (P1.00)
VBAT/1.2A: C27.2, TP_VBAT.TP, U3.2 (CELL), U3.3 (VDD)
VBAT/2.5C: C37.2, IC1.C2 (BAT)
VBUS/1.5D: C42.1, C43.1, D3.5 (VBUS), J4.A4_B9 (VBUS), J4.A9_B4 (VBUS)
VBUS/2.6D: C21.1, C38.2, IC1.A2 (IN), U1.P$AD2 (VBUS)
VREG: C23.2, C24.2, C39.2, IC1.B2 (SYS), IC9.A1 (EN), IC9.A2 (VIN_1), IC9.A3 (VIN_2), TP_VREG.TP

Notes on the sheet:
SWD
LiPo Charger
IMU
DC/DC
E-Paper Display Connector
3k3
Fuel Gauge
0.1uF
E-Paper Drive Circuit
0.47
2.2
10K
DMG2305UX-7
10k
Haptic Driver
5K1
USB C Connector & ESD Protection
Buttons

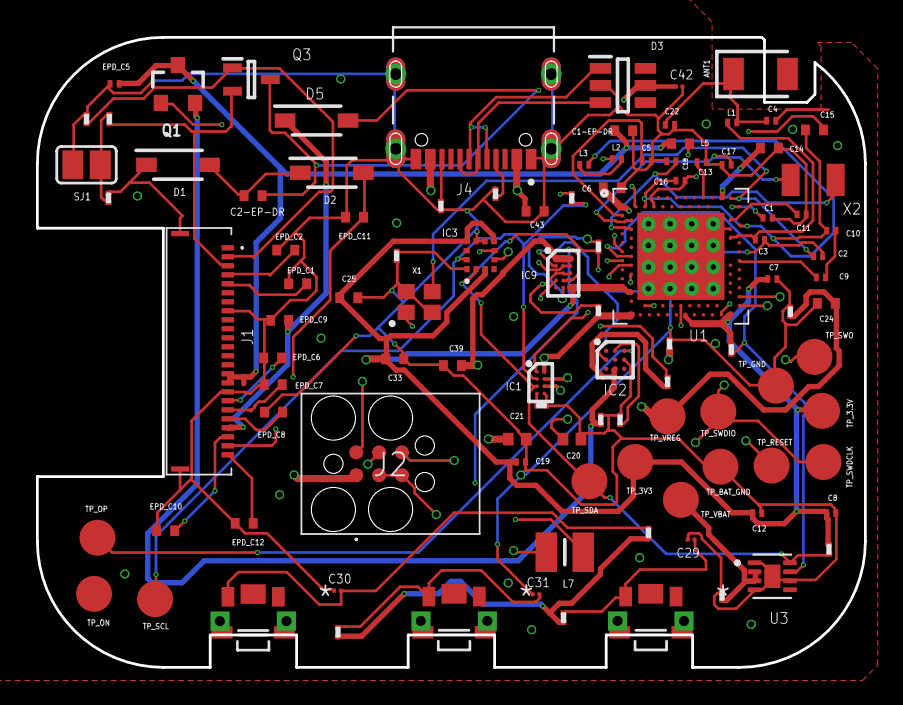
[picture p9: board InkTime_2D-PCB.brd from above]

Board: 4 copper layers, 46.0 x 35.0 mm, 105 parts (0 on the bottom side), 65 nets.

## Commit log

2026-04-21 Updated 2D-PCB Fixes #6
    [InkTime_2D-PCB.brd]
2026-04-21 Added images with the renders of the device
    Fixes #3
2026-04-21 Added mechanical files
    Fixes #2
    [InkTime_Assembly.f3z]
2026-04-21 Add schematic print-out
    Fixes #1
2026-04-21 Update Schematic
    Fixes #5
    [InkTime Schematic.sch]
2026-04-21 Enhance README with block diagram and BOM details
    Added detailed block diagram, BOM, system design, and hardware implementation sections to the README.

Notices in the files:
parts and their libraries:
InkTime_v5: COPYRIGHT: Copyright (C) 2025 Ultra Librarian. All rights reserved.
